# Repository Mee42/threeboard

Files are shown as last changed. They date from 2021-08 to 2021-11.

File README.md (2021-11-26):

## Threeboard

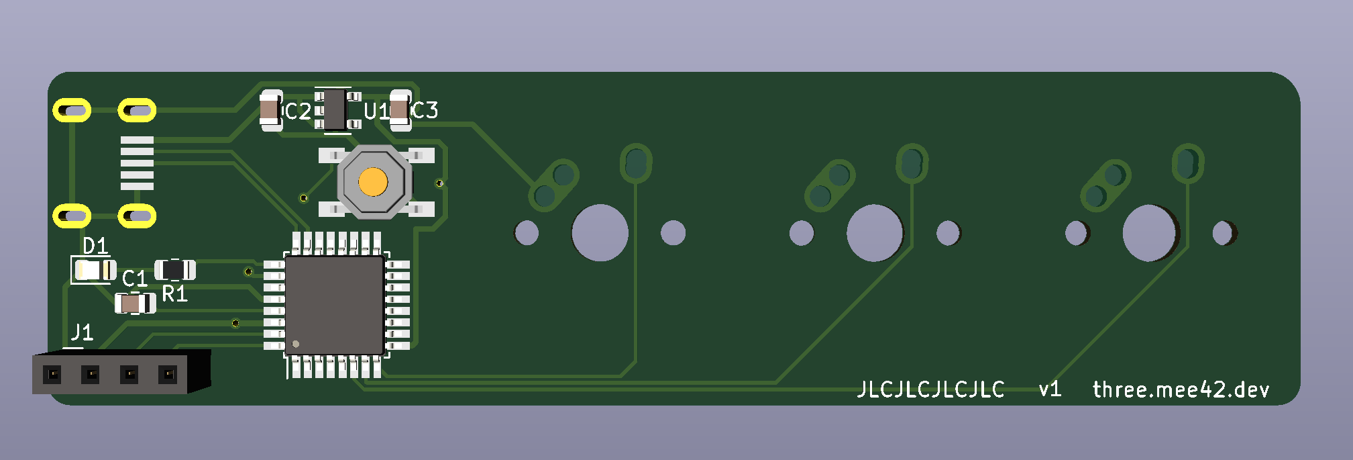
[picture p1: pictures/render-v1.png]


The v1 threeboard has been fully assembled and firmware is currently in developement. 
Firmware is in the `code/` directory and is written in C.

### KiCad instructions
PCB files are in the `pcb/` directory. Threeboard is designed on an ATSAMD21E17A arm microcontroller. A v2 board is in development

Both 
[random parts](https://github.com/ai03-2725/random-keyboard-parts.pretty)
and
[mx switch footprint](https://github.com/ai03-2725/MX_Alps_Hybrid.pretty)
are dependencies for the kicad files.

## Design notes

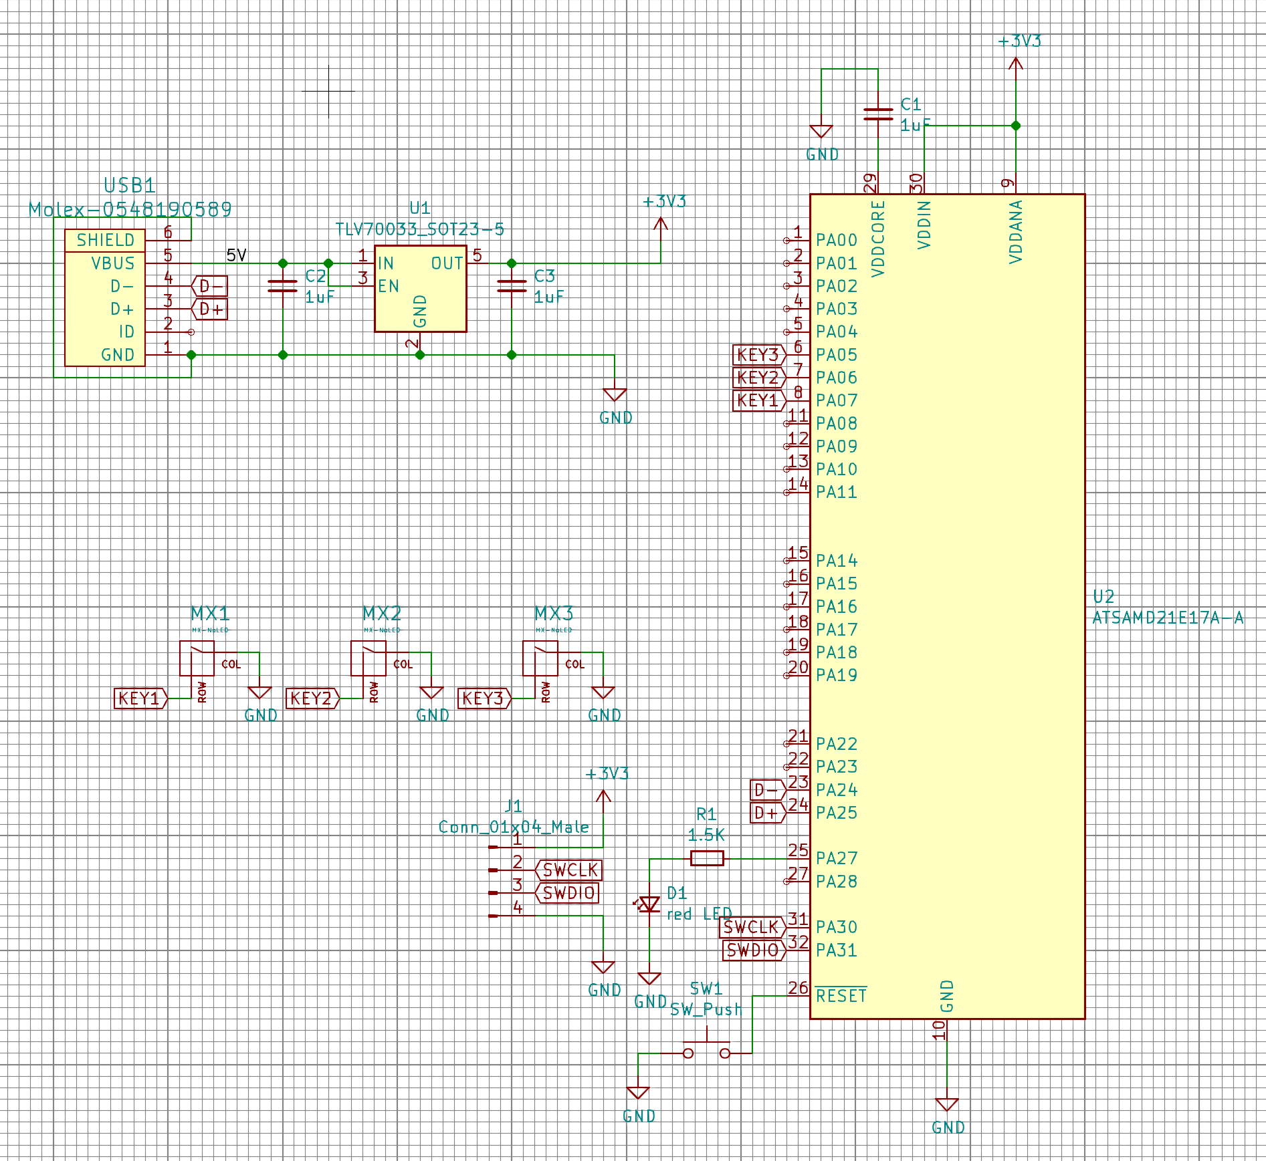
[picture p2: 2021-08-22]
pictures/schematic-v1.png

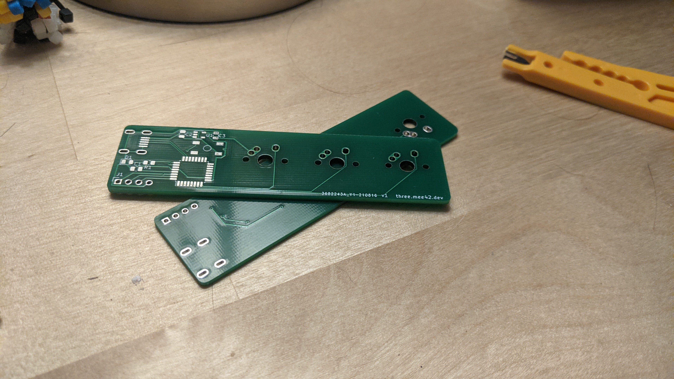
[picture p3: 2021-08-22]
pictures/pcb-irl-v1.png

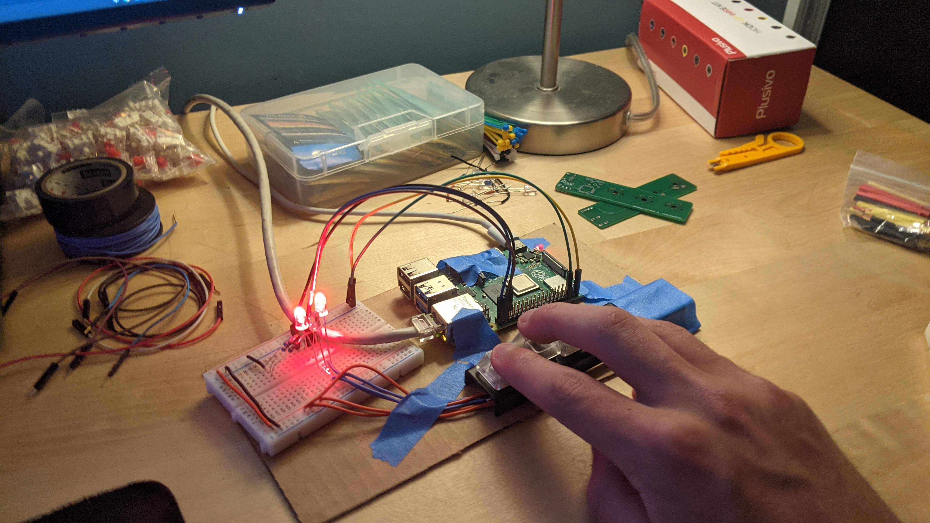
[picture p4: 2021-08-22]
pictures/v0.png

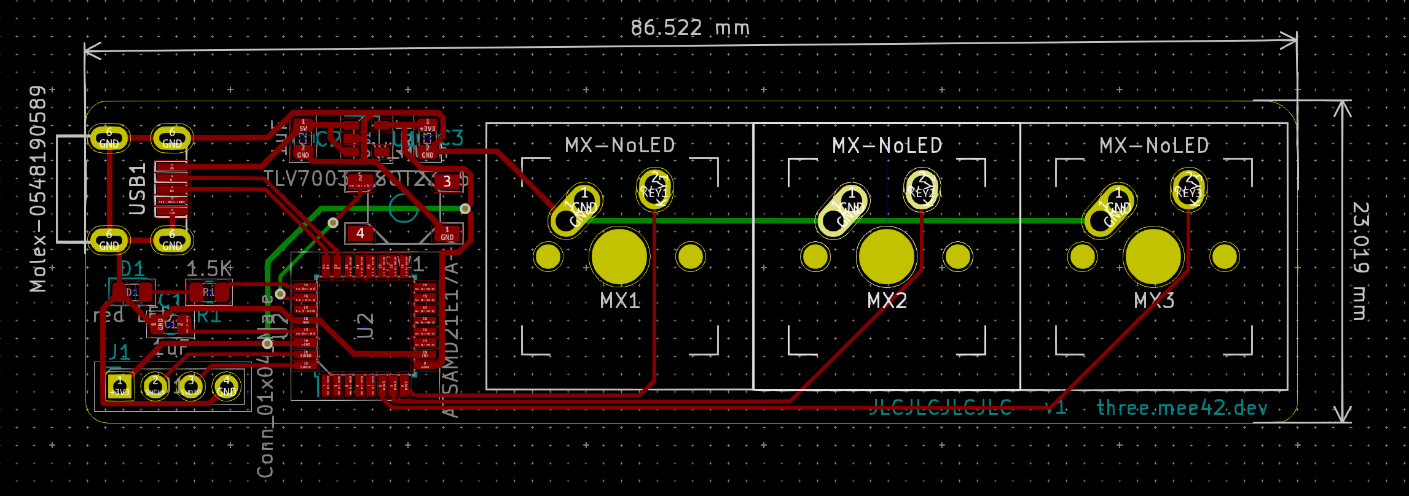
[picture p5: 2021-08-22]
pictures/pcb-v1.png

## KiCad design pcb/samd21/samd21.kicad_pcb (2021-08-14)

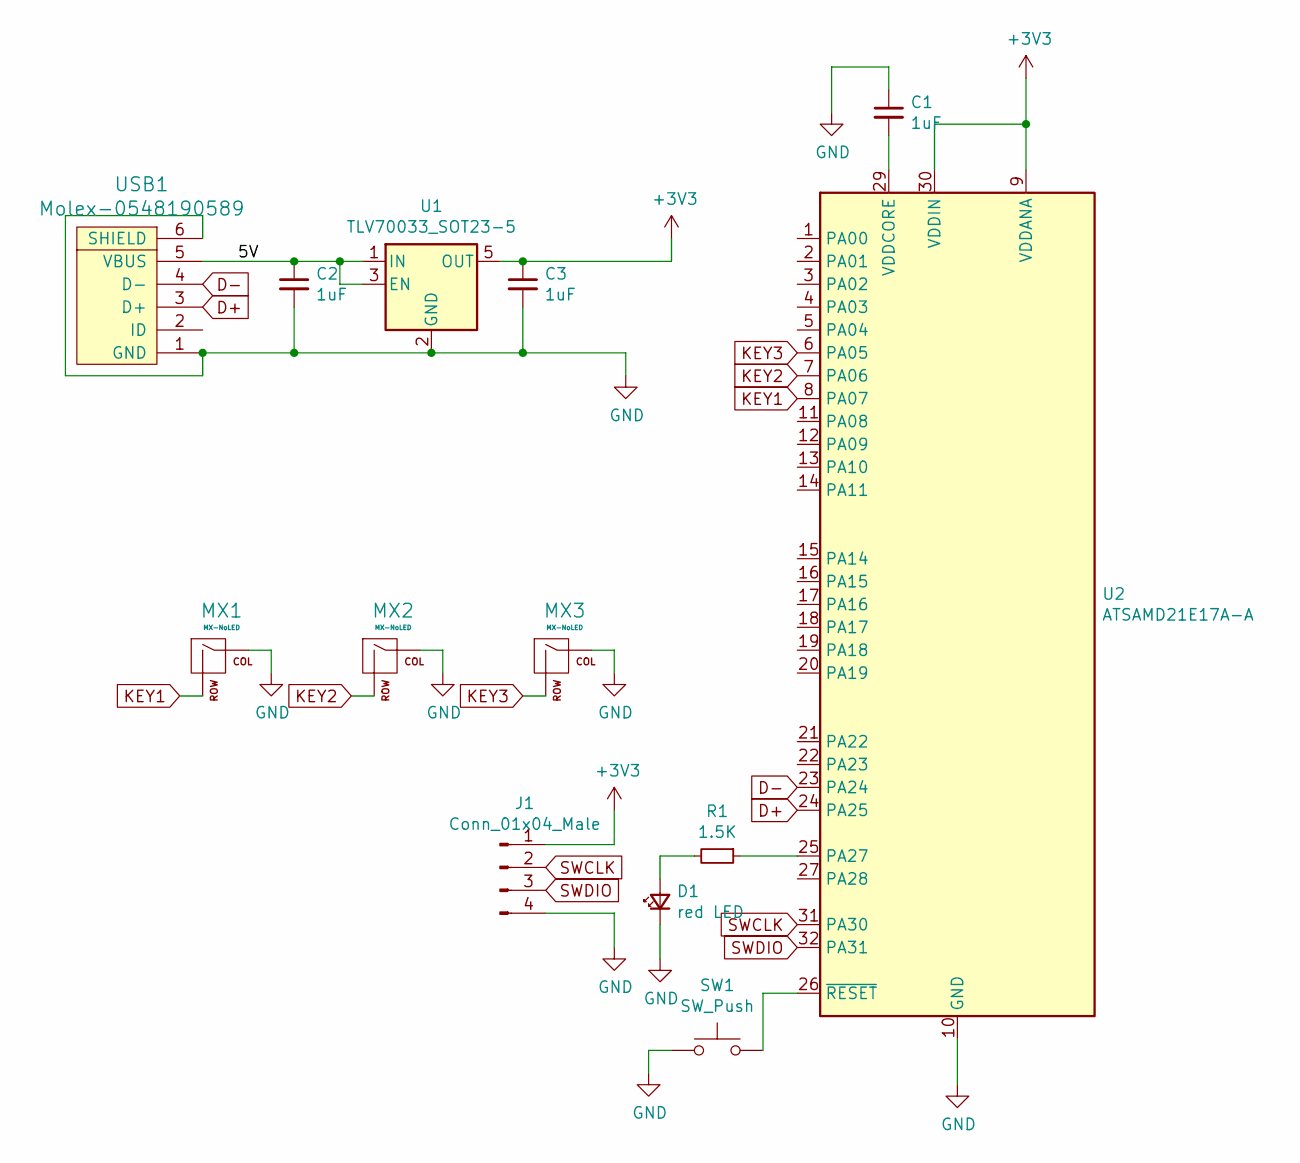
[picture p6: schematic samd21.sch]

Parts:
C1, C2, C3: 1uF; C_0805_2012Metric
D1: red LED; LED_0805_2012Metric
J1: Conn_01x04_Male; PinSocket_1x04_P2.54mm_Vertical
MX1, MX2, MX3: MX-NoLED; MX-1U-NoLED
R1: 1.5K; R_0805_2012Metric
SW1: SW_Push; SKQG-1155865
U1: TLV70033_SOT23-5; SOT-23-5
U2: ATSAMD21E17A-A; TQFP-32_7x7mm_P0.8mm
USB1: Molex-0548190589

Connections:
+3V3: C3.1, J1.1, U1.5 (OUT), U2.9 (VDDANA), U2.30 (VDDIN)
/5V: C2.1, U1.1 (IN), U1.3 (EN), USB1.5 (VBUS)
D+: U2.24 (PA25), USB1.3 (D+)
D-: U2.23 (PA24), USB1.4 (D-)
GND: C1.1, C2.2, C3.2, D1.1 (K), J1.4, MX1.1 (COL), MX2.1 (COL), MX3.1 (COL), SW1.1, U1.2 (GND), U2.10 (GND), U2.28 (GND), USB1.1 (GND), USB1.6 (SHIELD)
KEY1: MX1.2 (ROW), U2.8 (PA07)
KEY2: MX2.2 (ROW), U2.7 (PA06)
KEY3: MX3.2 (ROW), U2.6 (PA05)
unnamed: C1.2, U2.29 (VDDCORE)
unnamed: D1.2 (A), R1.2
unnamed: R1.1, U2.25 (PA27)
unnamed: SW1.2, U2.26 (~RESET)
SWCLK: J1.2, U2.31 (PA30)
SWDIO: J1.3, U2.32 (PA31)

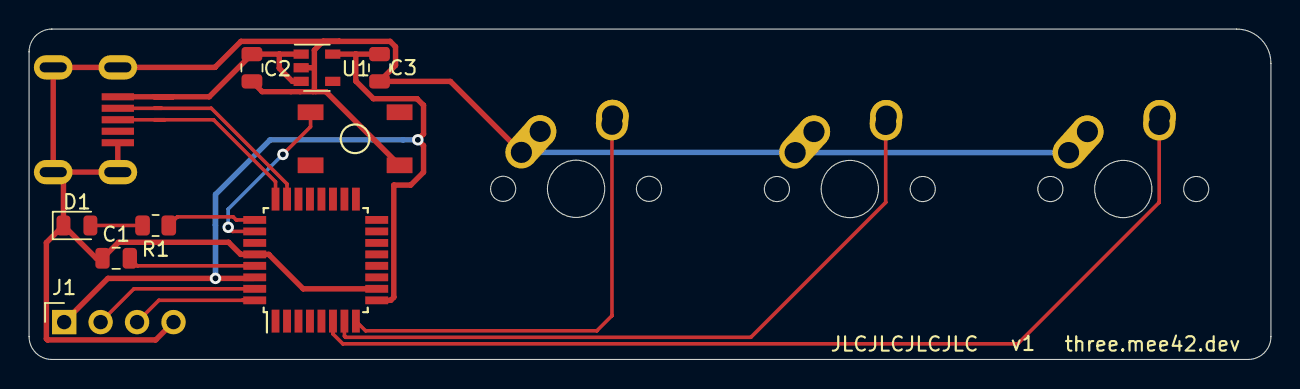
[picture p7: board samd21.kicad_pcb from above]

Board: 2 copper layers, 86.5 x 23.0 mm, 13 parts (0 on the bottom side), 14 nets.

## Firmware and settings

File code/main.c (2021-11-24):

#define true 1
#define false 0
#define bool _Bool

// so it goes first, for linking
__attribute__((section(".text.main"))) void main();
void halt();
void setup_global_variables();
void delay(int);
void blinkN(int, int);
void initGPIO();
void setLED(bool);
bool readPin();

extern char l_flash_data; // where the .data segment is in flash
extern char l_mem_data; // where the .data segment is in memory
extern char l_mem_data_end;  // the end of the .data segment in memory
 
// sizeof(long)      = 4
// sizeof(int)       = 4
// sizeof(long long) = 8

// memory
// stack starts at 0x20003FFF and grows down
// global variables start at 0x20000000 go up until l_mem_data_end
// heap starts at l_mem_data_end and grows up

volatile int* const post_tables  = (int*)0x41004400; // place we can configure the pins
volatile char* start_of_mem = (char*)(&l_mem_data_end); // where the heap (should) start


int x = 0xDEADBEAF; // goes into .data. Remove once we have actual rw data
int const y = 0xBABEDEAD; // goes into .rodata, read only

// do not return from main
// you will segfault
void main() {
    // this is needed to reset the stackpointer when debugging (otherwise it trends downwards)
    asm("ldr r0, =0x20003FFF");
    asm("mov sp, r0");
    delay(30000); // seems like the sram needs time to boot...
    // NEEDED, all global variables are garbage until this is called
    setup_global_variables();
    initGPIO();

    blinkN(5, 30000);
    while(true) {
        setLED(readPin());
    }
//    while(true) {
//        if(readPin()) {
//            blinkN(1, 100000);
//        } else {
//            blinkN(1, 10000);
//        }
//    }

    // do not remove
    halt();
}

// led  PA27
// key3 PA05
volatile char* const pincfg5 = ((char*)post_tables) + 0x40/*starting offset*/ + 0x5/*pin num*/;
void initGPIO() {
    post_tables[0x08 / sizeof(int*)] = 1 << 27; // DIRSET[27] = 1

    // the keys are configured with internal pull-up resistors, with the key connecting the pin to ground
    post_tables[0x04/sizeof(int*)] = 1 << 5; // DIRCLR[5] = 0
    post_tables[0x18/sizeof(int*)] = 1 << 5; // OUTSET[5] = 1
    *pincfg5 = 1 << 2; // pincfg5 bit 2 (PULLEN) = 1
    *pincfg5 |= 1 << 1; // pincfg5 bit 1 (INEN) = 1

    // DIR: 0     input pin
    // PULLEN: 1  pull pin
    // OUT: 1     pull up
    // INEN: 1    buffered
    
    // read state out of IN[bit y]
}
bool readPin() {
    return (post_tables[0x20/sizeof(int*)] & 0x20) != 0; // IN[5];
}

void setLED(bool state) {
    if(state) {
        post_tables[0x14 / sizeof(int*)] = 1 << 27;// OUTCLR[27]
    } else {
        post_tables[0x18 / sizeof(int*)] = 1 << 27; // OUTSET[27]
    }
}



void blinkN(int n, int delayTime) {
    int i = 0;
    while(i < n) {
        i++;
        setLED(true);
        delay(delayTime);
        setLED(false);
        delay(delayTime);
    }
}


void setup_global_variables() {
    int* start = (int*)(&l_flash_data);
    int* dest  = (int*)(&l_mem_data);
    int* end_dest = (int*)(&l_mem_data_end);
    do { // might be off-by-one error, should we do <=?
        asm("mov r7, r7");
        *dest = *start;
        dest++;
        start++;
    }while(dest != end_dest);
}

__attribute__((noinline)) void delay(int delayTime) {
    // delays ~0.5 seconds
    register int i = 0;
    while(i < delayTime) {
        i++;
        asm("");
    }
}


// busyloop the CPU, never exit
void halt() {
    while(1) {}
}

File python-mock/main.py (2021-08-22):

import time
import RPi.GPIO as GPIO
import sys




logFile = open('log.log', 'a')
def log(s):
    global logFile
    logFile.write(str(s))
    logFile.flush()

def error(str):
    raise RuntimeError(str)

log('\n\n\n\n\n\n\n    ----    program start    ----\n')


# state
mode = 0

# morse code state
inWord = False
buf = []

# modifier state
mods = []

def processKeystroke(state):
    global mode
    log("mode: " + str(mode) + " state: " + str(state) + "\n")
    if state == [1, 1, 1]:
        mode = 0
        mode0_morse_init()
    if state == [0, 1, 1]:
        # next mode
        mode = mode + 1
        if mode == 0:
            mode0_morse_init()
    else:
        if mode == 0:
            mode0_morse(state)
        elif mode == 1:
            mode1_modifiers(state)
        elif mode == 2:
            mode2_arrows(state)
        elif mode == 5:
            mode5_system(state)
        else:
            error("Can't find mode " + str(mode))

def mode0_morse_init():
    # runs whenever we enter this mode
    global inWord
    global buf
    inWord = False
    buf = []

def mode0_morse(state):
    global inWord
    global buf
    if state == [1, 0, 0] or state == [0, 1, 0]:
        isDit = 1 if state == [1, 0, 0] else 0
        buf.append(isDit)
        inWord = True
    elif state == [0, 0, 1] and buf == []:
        # space
        sys.stdout.write(" ")
        sys.stdout.flush()
    elif state == [0, 0, 1]:
        char = morseLookup(buf)
        buf = []
        if char == None:
            return # can't write obv
        inWord = False
        global mods
        if "shift" in mods:
            char = char.upper()
        if "ctrl" in mods or "alt" in mods or "win" in mods:
            log("can't handle mods " + str(mods) + " right now")
        mods = []
        sys.stdout.write(char)
        sys.stdout.flush()
    elif state == [1, 1, 0]:
        buf = []
        inWord = False

def mode1_modifiers_init():
    global buf
    global inWord
    buf = []
    inWord = False

def mode1_modifiers(state):
    global buf
    global mods
    global mode
    global inWord
    if state == [1, 0, 0] or state == [0, 1, 0]:
        buf.append(1 if state == [1, 0, 0] else 0) # 1 -> ctrl, 1 1 -> win, 0 -> shift, 0 0 -> alt
        inWord = True
    elif state == [0, 0, 1]:
        if buf == []:
            log("got empty buf on 001 in mode1") # TODO what do we do in case 111 011 001?
        else:
            mod = None 
            if buf == [1]:
                mod = 'ctrl'
            elif buf == [1, 1]:
                mod = 'win'
            elif buf == [0]:
                mod = 'shift'
            elif buf == [0, 0]:
                mod = 'alt'
            else:
                error("unknown modifier " + str(buf))
            log("adding modifier " + mod + "\n")
            mods.append(mod)
            mode = 0
            inWord = False
            buf = []



def mode2_arrows(state):
    pass

def mode5_system(state):
    pass

def morseLookup(arr):
    # chonk lookup
    string = reduce(lambda a, b: a + str(b), arr, "")
    log("looking up " + string + "\n")
    if string in morseObj:
        return morseObj[string]
    log("unknown sequence: " + string)
    return None

# a = dit
# b = dah
morseObj = {
        "10": "a",
        "0111": "b",
        "0101": "c",
        "011": "d",
        "1": "e",
        "1101": "f",
        "001": "g",
        "1111": "h",
        "11": "i",
        "1000": "j",
        "010": "k",
        "1011": "l",
        "00": "m",
        "01": "n",
        "000": "o",
        "1001": "p",
        "0010": "q",
        "101": "r",
        "111": "s",
        "0": "t",
        "110": "u",
        "1110": "v",
        "100": "w",
        "0110": "x",
        "0100": "y",
        "0011": "z",
        "10000": "1",
        "11000": "2",
        "11100": "3",
        "11110": "4",
        "11111": "5",
        "01111": "6",
        "00111": "7",
        "00011": "8",
        "00001": "9",
        "00000": "10",
        "101010": ".",
        "001100": ",",
        "000111": ":",
        "110011": ":",
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

# special ones
#        aaaaaaaa ERRROR
#        aaaoa    UNDERSTAND
#        oao INVITATION TO TRANSIT
#        aoaaa WAIT
#        aaaoao END OF WORK
#        oaoao STARTING SIGNAL

        
    }








# set up gpio
GPIO.setmode(GPIO.BCM)

one = 16
two = 20
three = 21
statusPin = 12

GPIO.setup(one, GPIO.IN, pull_up_down=GPIO.PUD_DOWN)
GPIO.setup(two, GPIO.IN, pull_up_down=GPIO.PUD_DOWN)
GPIO.setup(three, GPIO.IN, pull_up_down=GPIO.PUD_DOWN)
GPIO.setup(statusPin, GPIO.OUT)

def setStatusLeds(value):
    GPIO.output(statusPin, value)

lastState = [0, 0, 0]

try:
    while True:
        time.sleep(0.001)
        state = [GPIO.input(x) for x in [one, two, three]]
        if state == lastState:
            continue
        for n in range(0, 3):
            if state[n] > lastState[n]:
                lastState[n] = 1
        if sum(state) == 0 and sum(lastState) > 0:
            # print(lastState[0] * 4 + lastState[1] * 2 + lastState[2])
            try:
                processKeystroke(lastState)
            except Exception as e:
                log("ERROR: " + str(e) + "\n")
            lastState = [0, 0, 0]
except KeyboardInterrupt:
    pass

log('exited')
GPIO.cleanup()
logFile.close()

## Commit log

2021-08-13 starting samd21 version
    [samd21.kicad_pcb, samd21.sch]
2021-08-13 working on samd21 model
    [samd21.sch]
2021-08-13 got most of the parts down..
    [samd21.kicad_pcb, samd21.sch]
2021-08-14 v1-dev pcb+schem complete. not finished
    [samd21.kicad_pcb, samd21.sch]
2021-08-14 moved switches from 3v3 to GND, using pullup
    [samd21-B_Cu.gbr, samd21-B_Mask.gbr, samd21-B_Paste.gbr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]
2021-08-22 cleaned repo
    [samd21-B_Cu.gbr, samd21-B_Mask.gbr, samd21-B_Paste.gbr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]
2021-11-07 made arm work
2021-11-22 last commit before switching to C-only build
2021-11-24 SUCCESS led is tied to switch
2021-11-26 cleaned up
    [samd21-NPTH.drl, samd21-PTH.drl, samd21-job.gbrjob]
